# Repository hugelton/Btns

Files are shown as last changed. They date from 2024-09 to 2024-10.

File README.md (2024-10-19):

# Btns
Buttons board compatible with monome grid



## Overview
Btns is a clone of [Monome Grid]([url](https://monome.org)).

**⚠️ It doesn't support 16 levels of LED grey scale. It just turns on or off. **

## Make
### Hardware
Make your board from the gerber.

#### BOM
+ Raspberry Pi Pico (or same footprint clones) * 1
+ TSHD-T-2.8T2 SMD Tact switch with LED * 64
+ 1N4148W (SOD-123) SMD diode * 64
+ TM1640 LED segments driver * 1
+ 10k THT resistor * 2
+ 10ohm THT resistor * 1
+ MPU-6050 (optional for tilt mod)
+ VXO7803-500 (optional)
+ Eurorack 16pin Bus Conn (optional)

### Firmware
upload the firmware to Pico from [Release]([url](https://github.com/hugelton/Btns/releases/tag/0.3)). 

### Test (on Norns)
Please use okyeron's [grid-test](https://github.com/okyeron/grid-test) 

```
;install https://github.com/okyeron/grid-test
```

### Plans
+ support MPU-6050 (tilt)
+ support multi-PWM
+ support other buttons

## Acknowledgments
Based on okyeron's [neotrellis-monome](https://github.com/okyeron/neotrellis-monome/) project.

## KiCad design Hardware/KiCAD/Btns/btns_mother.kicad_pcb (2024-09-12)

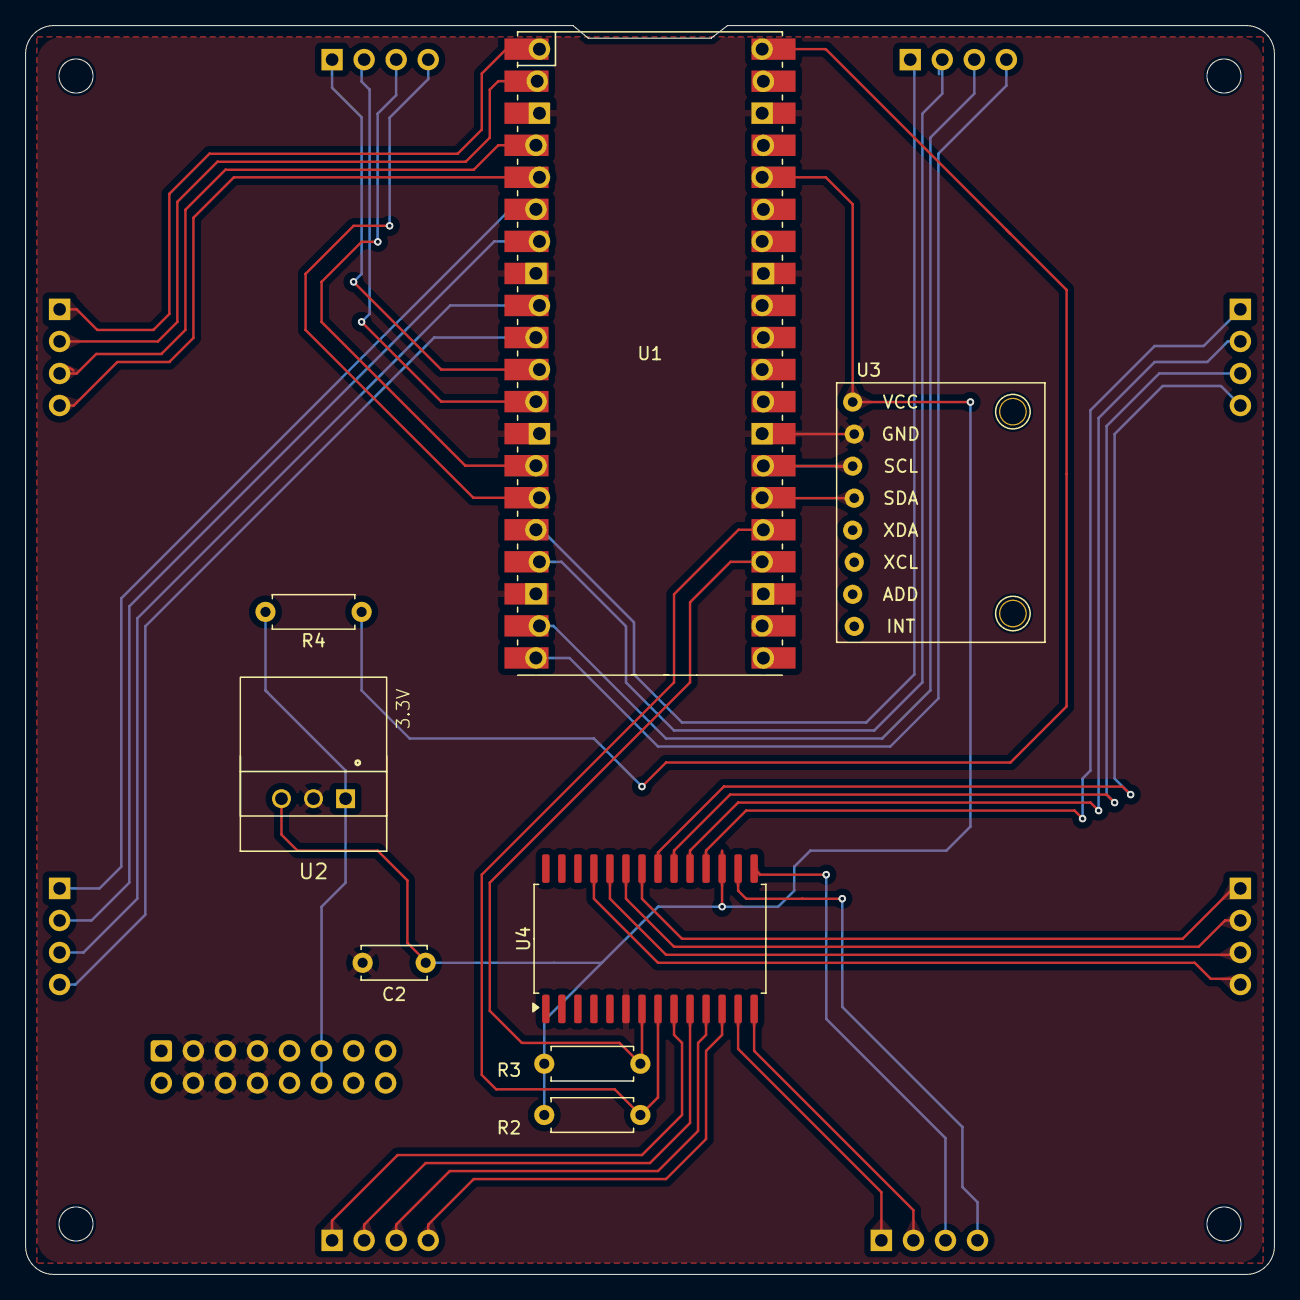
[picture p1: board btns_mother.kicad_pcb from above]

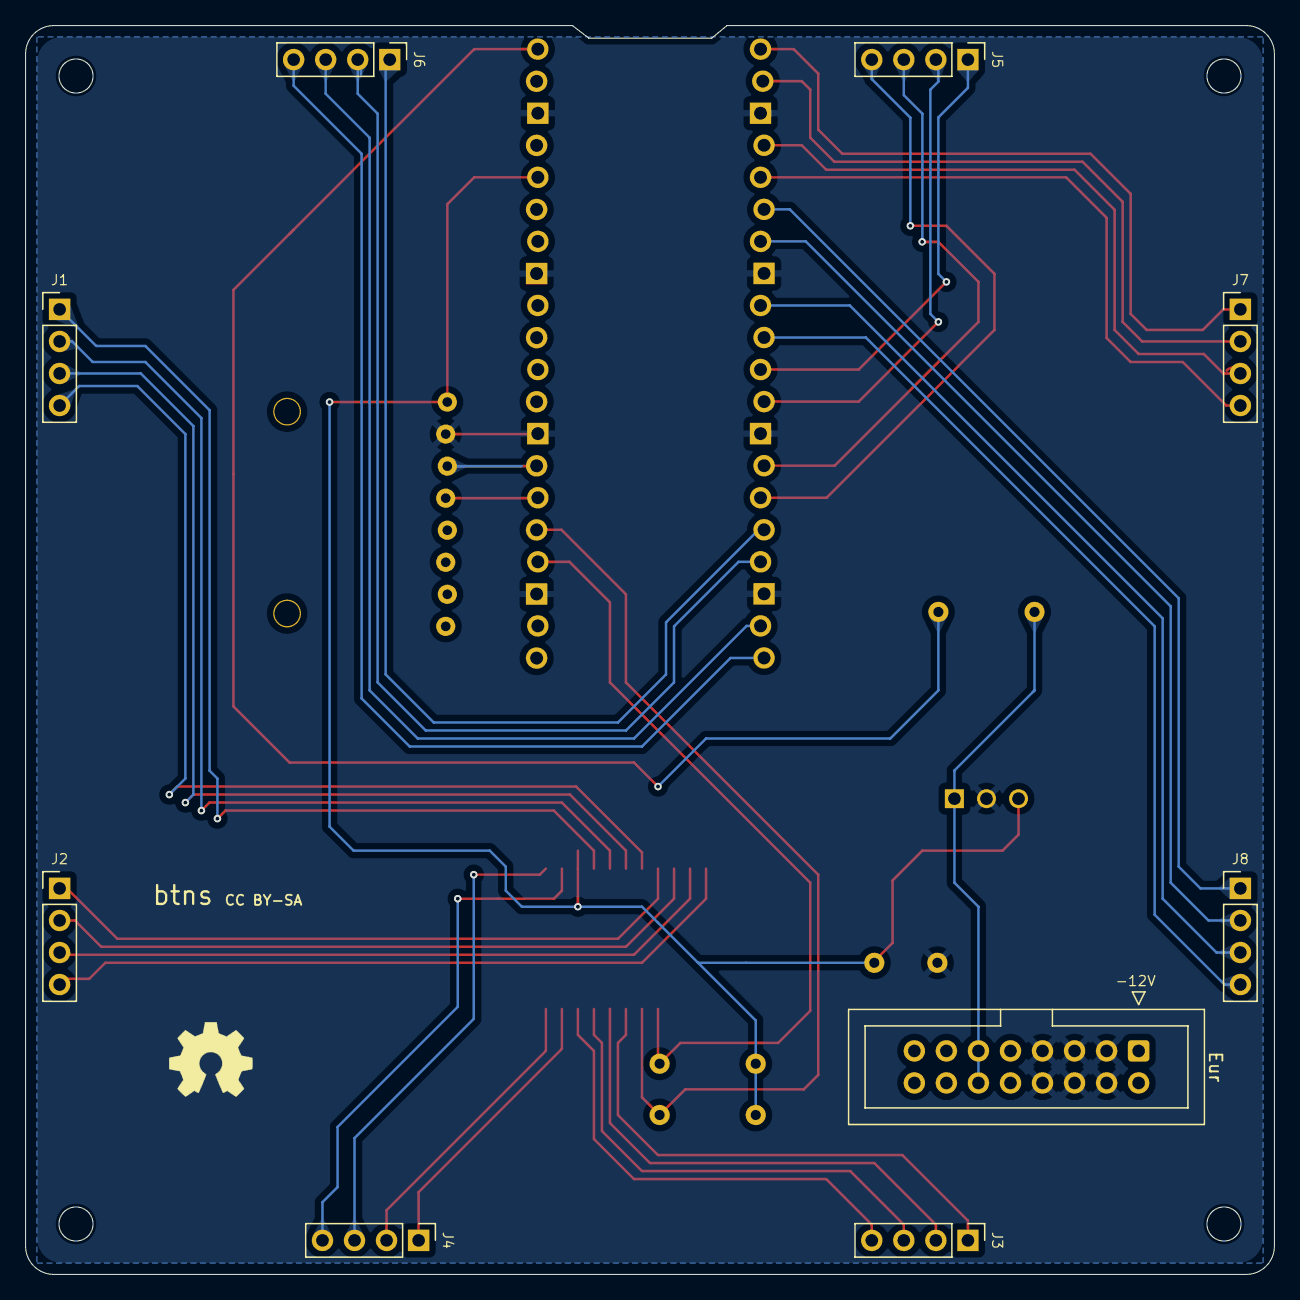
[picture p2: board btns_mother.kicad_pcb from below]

Board: 2 copper layers, 99.0 x 99.0 mm, 17 parts (9 on the bottom side), 40 nets.

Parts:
C2: 10uF; C_Disc_D5.0mm_W2.5mm_P5.00mm
Eur: IDC-Header_2x08_P2.54mm_Vertical
J1, J2, J3, J4, J5, J6, J7, J8: Conn_01x04_Pin; PinHeader_1x04_P2.54mm_Vertical
R2, R3: 10k; R_Axial_DIN0207_L6.3mm_D2.5mm_P7.62mm_Horizontal
R4: 10; R_Axial_DIN0207_L6.3mm_D2.5mm_P7.62mm_Horizontal
U1: Pico; RPi_Pico
U2: VX78_O78
U3: module_mpu6050
U4: TM1640; SOP-28_8.4x18.16mm_P1.27mm

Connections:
+3V3: C2.1, R2.1, R3.1, U1.36 (3V3), U2.3 (+VOUT/GND), U3.1 (VCC), U4.17 (VDD)
GND: C2.2, Eur.3, Eur.4, Eur.5, Eur.6, Eur.7, Eur.8, U1.3 (GND), U1.8 (GND), U1.13 (GND), U1.18 (GND), U1.23 (GND), U1.28 (GND), U1.33 (AGND), U1.38 (GND), U2.2 (GND/-VOUT), U3.2 (GND), U4.6 (VSS)
I2C0_SCL: U1.27 (GPIO21), U3.3 (SCL)
I2C0_SDA: U1.26 (GPIO20), U3.4 (SDA)
LED_COL_1: J3.1, U4.9 (SEG1)
LED_COL_2: J3.2, U4.10 (SEG2)
LED_COL_3: J3.3, U4.11 (SEG3)
LED_COL_4: J3.4, U4.12 (SEG4)
LED_COL_5: J4.1, U4.13 (SEG5)
LED_COL_6: J4.2, U4.14 (SEG6)
LED_COL_7: J4.3, U4.15 (SEG7)
LED_COL_8: J4.4, U4.16 (SEG8)
LED_ROW_1: J1.1, U4.18 (GRID1)
LED_ROW_2: J1.2, U4.19 (GRID2)
LED_ROW_3: J1.3, U4.20 (GRID3)
LED_ROW_4: J1.4, U4.21 (GRID4)
LED_ROW_5: J2.1, U4.22 (GRID5)
LED_ROW_6: J2.2, U4.23 (GRID6)
LED_ROW_7: J2.3, U4.24 (GRID7)
LED_ROW_8: J2.4, U4.25 (GRID8)
unnamed: Eur.11, Eur.12, R4.2, U2.1 (+VIN)
SW_COL_1: J5.1, U1.11 (GPIO8)
SW_COL_2: J5.2, U1.12 (GPIO9)
SW_COL_3: J5.3, U1.14 (GPIO10)
SW_COL_4: J5.4, U1.15 (GPIO11)
SW_COL_5: J6.1, U1.16 (GPIO12)
SW_COL_6: J6.2, U1.17 (GPIO13)
SW_COL_7: J6.3, U1.19 (GPIO14)
SW_COL_8: J6.4, U1.20 (GPIO15)
SW_ROW_1: J7.1, U1.1 (GPIO0)
SW_ROW_2: J7.2, U1.2 (GPIO1)
SW_ROW_3: J7.3, U1.4 (GPIO2)
SW_ROW_4: J7.4, U1.5 (GPIO3)
SW_ROW_5: J8.1, U1.6 (GPIO4)
SW_ROW_6: J8.2, U1.7 (GPIO5)
SW_ROW_7: J8.3, U1.9 (GPIO6)
SW_ROW_8: J8.4, U1.10 (GPIO7)
TM_D: R3.2, U1.24 (GPIO18), U4.7 (DIN)
TM_SCLK: R2.2, U1.25 (GPIO19), U4.8 (SCLK)
VBUS: R4.1, U1.40 (VBUS)

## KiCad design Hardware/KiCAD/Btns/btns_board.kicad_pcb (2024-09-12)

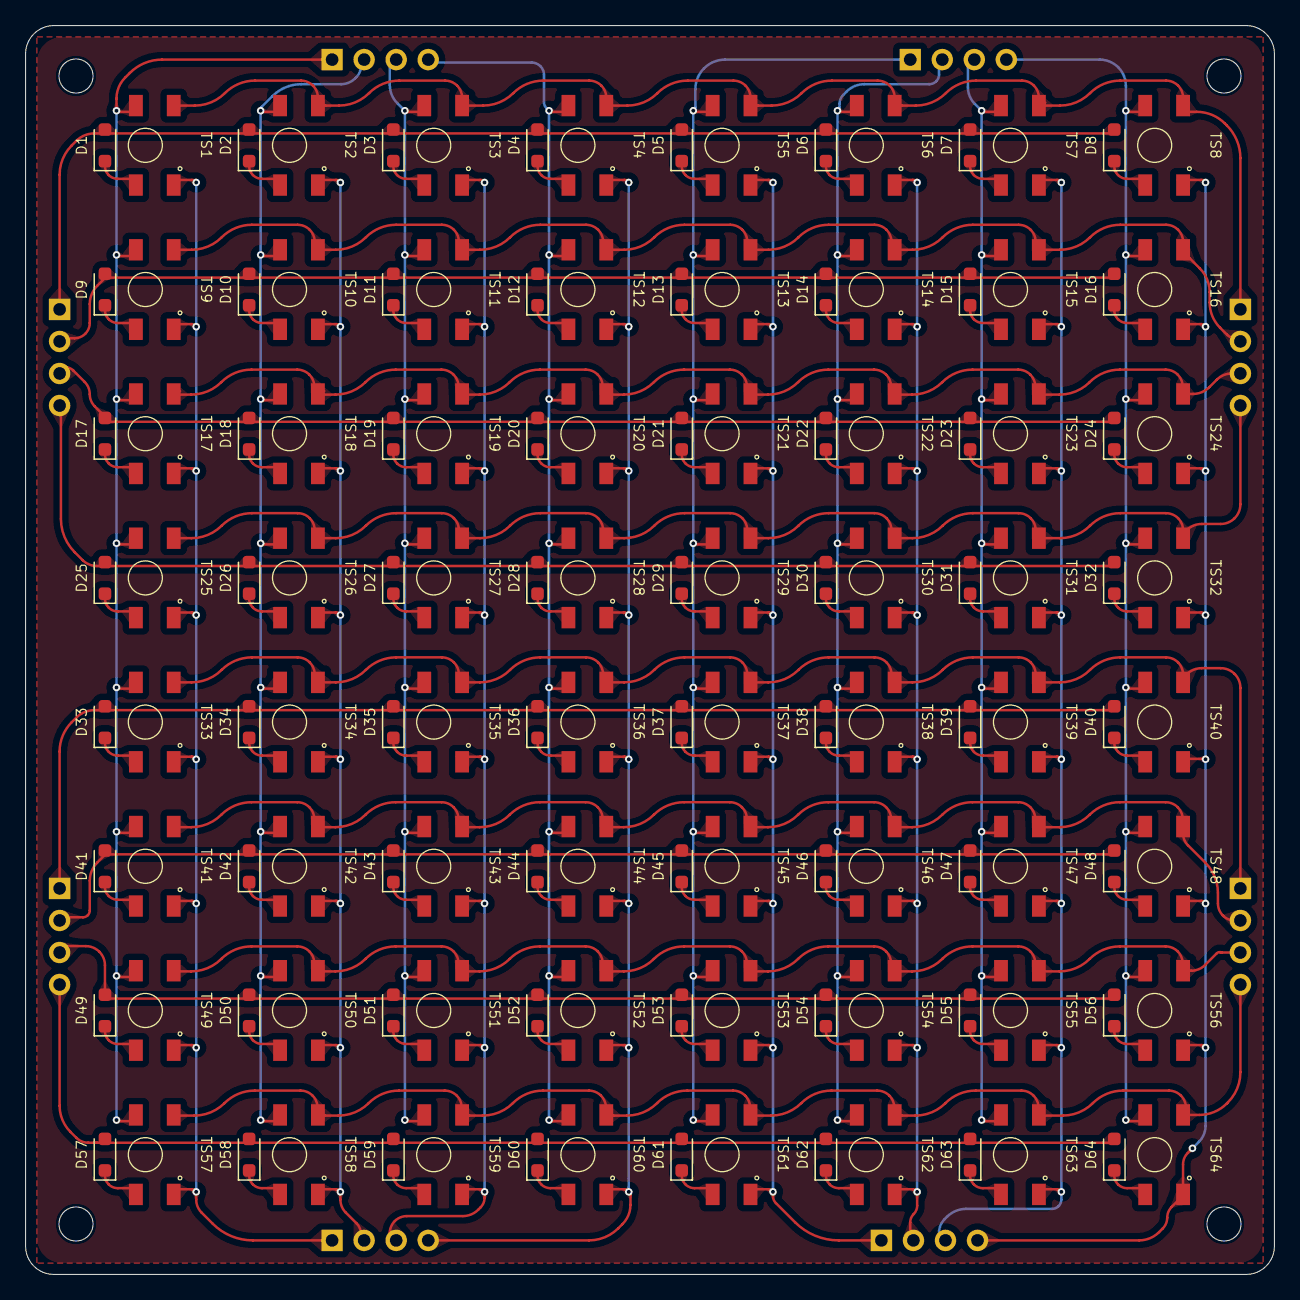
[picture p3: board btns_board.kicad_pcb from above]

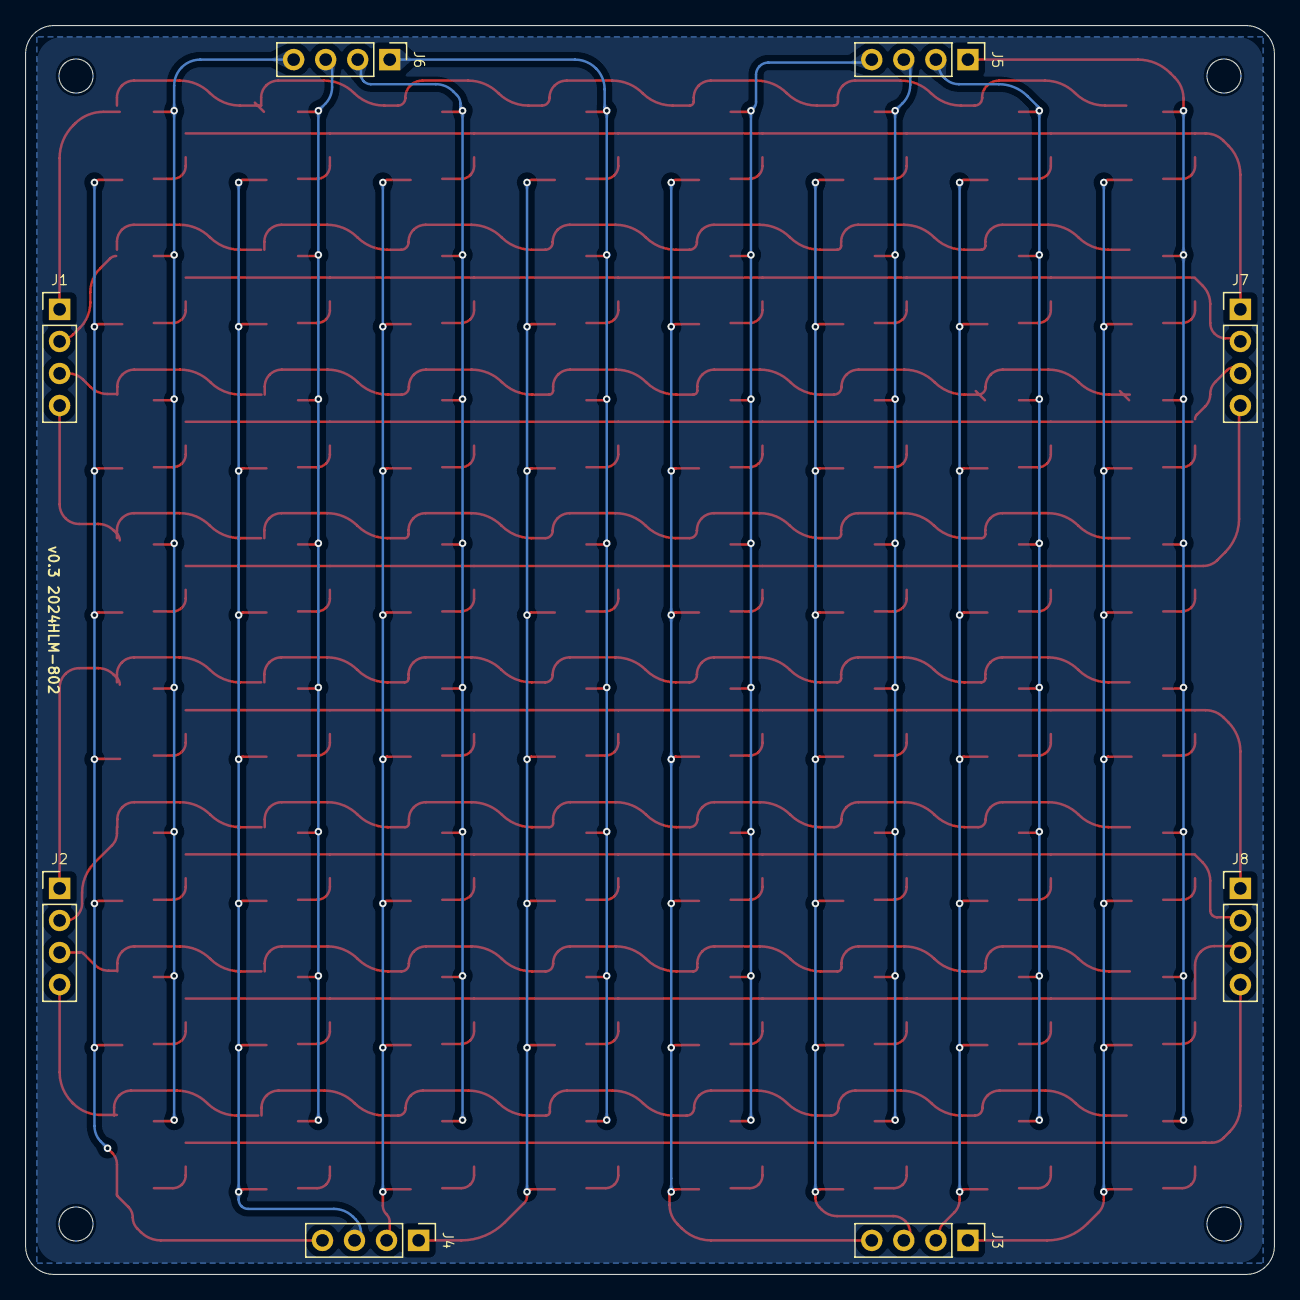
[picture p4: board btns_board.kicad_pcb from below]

Board: 2 copper layers, 99.0 x 99.0 mm, 136 parts (8 on the bottom side), 96 nets.

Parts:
D1, D2, D3, D4, D5, D6, D7, D8, D9, D10, D11, D12, D13, D14, D15, D16, D17, D18, D19, D20, D21, D22, D23, D24, D25, D26, D27, D28, D29, D30, D31, D32, D33, D34, D35, D36, D37, D38, D39, D40, D41, D42, D43, D44, D45, D46, D47, D48, D49, D50, D51, D52, D53, D54, D55, D56, D57, D58, D59, D60, D61, D62, D63, D64: 1N4148WS; D_SOD-323_HandSoldering
J1, J2, J3, J4, J5, J6, J7, J8: Conn_01x04_Pin; PinHeader_1x04_P2.54mm_Vertical
TS1, TS2, TS3, TS4, TS5, TS6, TS7, TS8, TS9, TS10, TS11, TS12, TS13, TS14, TS15, TS16, TS17, TS18, TS19, TS20, TS21, TS22, TS23, TS24, TS25, TS26, TS27, TS28, TS29, TS30, TS31, TS32, TS33, TS34, TS35, TS36, TS37, TS38, TS39, TS40, TS41, TS42, TS43, TS44, TS45, TS46, TS47, TS48, TS49, TS50, TS51, TS52, TS53, TS54, TS55, TS56, TS57, TS58, TS59, TS60, TS61, TS62, TS63, TS64: TSHD-T-2.8T2--6H

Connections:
LED_COL_1: J3.1, TS1.3 (L1), TS9.3 (L1), TS17.3 (L1), TS25.3 (L1), TS33.3 (L1), TS41.3 (L1), TS49.3 (L1), TS57.3 (L1)
LED_COL_2: J3.2, TS2.3 (L1), TS10.3 (L1), TS18.3 (L1), TS26.3 (L1), TS34.3 (L1), TS42.3 (L1), TS50.3 (L1), TS58.3 (L1)
LED_COL_3: J3.3, TS3.3 (L1), TS11.3 (L1), TS19.3 (L1), TS27.3 (L1), TS35.3 (L1), TS43.3 (L1), TS51.3 (L1), TS59.3 (L1)
LED_COL_4: J3.4, TS4.3 (L1), TS12.3 (L1), TS20.3 (L1), TS28.3 (L1), TS36.3 (L1), TS44.3 (L1), TS52.3 (L1), TS60.3 (L1)
LED_COL_5: J4.1, TS5.3 (L1), TS13.3 (L1), TS21.3 (L1), TS29.3 (L1), TS37.3 (L1), TS45.3 (L1), TS53.3 (L1), TS61.3 (L1)
LED_COL_6: J4.2, TS6.3 (L1), TS14.3 (L1), TS22.3 (L1), TS30.3 (L1), TS38.3 (L1), TS46.3 (L1), TS54.3 (L1), TS62.3 (L1)
LED_COL_7: J4.3, TS7.3 (L1), TS15.3 (L1), TS23.3 (L1), TS31.3 (L1), TS39.3 (L1), TS47.3 (L1), TS55.3 (L1), TS63.3 (L1)
LED_COL_8: J4.4, TS8.3 (L1), TS16.3 (L1), TS24.3 (L1), TS32.3 (L1), TS40.3 (L1), TS48.3 (L1), TS56.3 (L1), TS64.3 (L1)
LED_ROW_1: J1.1, TS1.4 (L2), TS2.4 (L2), TS3.4 (L2), TS4.4 (L2), TS5.4 (L2), TS6.4 (L2), TS7.4 (L2), TS8.4 (L2)
LED_ROW_2: J1.2, TS9.4 (L2), TS10.4 (L2), TS11.4 (L2), TS12.4 (L2), TS13.4 (L2), TS14.4 (L2), TS15.4 (L2), TS16.4 (L2)
LED_ROW_3: J1.3, TS17.4 (L2), TS18.4 (L2), TS19.4 (L2), TS20.4 (L2), TS21.4 (L2), TS22.4 (L2), TS23.4 (L2), TS24.4 (L2)
LED_ROW_4: J1.4, TS25.4 (L2), TS26.4 (L2), TS27.4 (L2), TS28.4 (L2), TS29.4 (L2), TS30.4 (L2), TS31.4 (L2), TS32.4 (L2)
LED_ROW_5: J2.1, TS33.4 (L2), TS34.4 (L2), TS35.4 (L2), TS36.4 (L2), TS37.4 (L2), TS38.4 (L2), TS39.4 (L2), TS40.4 (L2)
LED_ROW_6: J2.2, TS41.4 (L2), TS42.4 (L2), TS43.4 (L2), TS44.4 (L2), TS45.4 (L2), TS46.4 (L2), TS47.4 (L2), TS48.4 (L2)
LED_ROW_7: J2.3, TS49.4 (L2), TS50.4 (L2), TS51.4 (L2), TS52.4 (L2), TS53.4 (L2), TS54.4 (L2), TS55.4 (L2), TS56.4 (L2)
LED_ROW_8: J2.4, TS57.4 (L2), TS58.4 (L2), TS59.4 (L2), TS60.4 (L2), TS61.4 (L2), TS62.4 (L2), TS63.4 (L2), TS64.4 (L2)
unnamed: D1.1 (K), TS1.1
unnamed: D2.1 (K), TS2.1
unnamed: D3.1 (K), TS3.1
unnamed: D4.1 (K), TS4.1
unnamed: D5.1 (K), TS5.1
unnamed: D6.1 (K), TS6.1
unnamed: D7.1 (K), TS7.1
unnamed: D8.1 (K), TS8.1
unnamed: D9.1 (K), TS9.1
unnamed: D10.1 (K), TS10.1
unnamed: D11.1 (K), TS11.1
unnamed: D12.1 (K), TS12.1
unnamed: D13.1 (K), TS13.1
unnamed: D14.1 (K), TS14.1
unnamed: D15.1 (K), TS15.1
unnamed: D16.1 (K), TS16.1
unnamed: D17.1 (K), TS17.1
unnamed: D18.1 (K), TS18.1
unnamed: D19.1 (K), TS19.1
unnamed: D20.1 (K), TS20.1
unnamed: D21.1 (K), TS21.1
unnamed: D22.1 (K), TS22.1
unnamed: D23.1 (K), TS23.1
unnamed: D24.1 (K), TS24.1
unnamed: D25.1 (K), TS25.1
unnamed: D26.1 (K), TS26.1
unnamed: D27.1 (K), TS27.1
unnamed: D28.1 (K), TS28.1
unnamed: D29.1 (K), TS29.1
unnamed: D30.1 (K), TS30.1
unnamed: D31.1 (K), TS31.1
unnamed: D32.1 (K), TS32.1
unnamed: D33.1 (K), TS33.1
unnamed: D34.1 (K), TS34.1
unnamed: D35.1 (K), TS35.1
unnamed: D36.1 (K), TS36.1
unnamed: D37.1 (K), TS37.1
unnamed: D38.1 (K), TS38.1
unnamed: D39.1 (K), TS39.1
unnamed: D40.1 (K), TS40.1
unnamed: D41.1 (K), TS41.1
unnamed: D42.1 (K), TS42.1
unnamed: D43.1 (K), TS43.1
unnamed: D44.1 (K), TS44.1
unnamed: D45.1 (K), TS45.1
unnamed: D46.1 (K), TS46.1
unnamed: D47.1 (K), TS47.1
unnamed: D48.1 (K), TS48.1
unnamed: D49.1 (K), TS49.1
unnamed: D50.1 (K), TS50.1
unnamed: D51.1 (K), TS51.1
unnamed: D52.1 (K), TS52.1
unnamed: D53.1 (K), TS53.1
unnamed: D54.1 (K), TS54.1
unnamed: D55.1 (K), TS55.1
unnamed: D56.1 (K), TS56.1
unnamed: D57.1 (K), TS57.1
unnamed: D58.1 (K), TS58.1
unnamed: D59.1 (K), TS59.1
unnamed: D60.1 (K), TS60.1
unnamed: D61.1 (K), TS61.1
unnamed: D62.1 (K), TS62.1
unnamed: D63.1 (K), TS63.1
unnamed: D64.1 (K), TS64.1
SW_COL_1: J5.1, TS1.2, TS9.2, TS17.2, TS25.2, TS33.2, TS41.2, TS49.2, TS57.2
SW_COL_2: J5.2, TS2.2, TS10.2, TS18.2, TS26.2, TS34.2, TS42.2, TS50.2, TS58.2
SW_COL_3: J5.3, TS3.2, TS11.2, TS19.2, TS27.2, TS35.2, TS43.2, TS51.2, TS59.2
SW_COL_4: J5.4, TS4.2, TS12.2, TS20.2, TS28.2, TS36.2, TS44.2, TS52.2, TS60.2
SW_COL_5: J6.1, TS5.2, TS13.2, TS21.2, TS29.2, TS37.2, TS45.2, TS53.2, TS61.2
SW_COL_6: J6.2, TS6.2, TS14.2, TS22.2, TS30.2, TS38.2, TS46.2, TS54.2, TS62.2
SW_COL_7: J6.3, TS7.2, TS15.2, TS23.2, TS31.2, TS39.2, TS47.2, TS55.2, TS63.2
SW_COL_8: J6.4, TS8.2, TS16.2, TS24.2, TS32.2, TS40.2, TS48.2, TS56.2, TS64.2
SW_ROW_1: D1.2 (A), D2.2 (A), D3.2 (A), D4.2 (A), D5.2 (A), D6.2 (A), D7.2 (A), D8.2 (A), J7.1
SW_ROW_2: D9.2 (A), D10.2 (A), D11.2 (A), D12.2 (A), D13.2 (A), D14.2 (A), D15.2 (A), D16.2 (A), J7.2
SW_ROW_3: D17.2 (A), D18.2 (A), D19.2 (A), D20.2 (A), D21.2 (A), D22.2 (A), D23.2 (A), D24.2 (A), J7.3
SW_ROW_4: D25.2 (A), D26.2 (A), D27.2 (A), D28.2 (A), D29.2 (A), D30.2 (A), D31.2 (A), D32.2 (A), J7.4
SW_ROW_5: D33.2 (A), D34.2 (A), D35.2 (A), D36.2 (A), D37.2 (A), D38.2 (A), D39.2 (A), D40.2 (A), J8.1
SW_ROW_6: D41.2 (A), D42.2 (A), D43.2 (A), D44.2 (A), D45.2 (A), D46.2 (A), D47.2 (A), D48.2 (A), J8.2
SW_ROW_7: D49.2 (A), D50.2 (A), D51.2 (A), D52.2 (A), D53.2 (A), D54.2 (A), D55.2 (A), D56.2 (A), J8.3
SW_ROW_8: D57.2 (A), D58.2 (A), D59.2 (A), D60.2 (A), D61.2 (A), D62.2 (A), D63.2 (A), D64.2 (A), J8.4

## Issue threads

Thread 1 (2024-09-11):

CAD files for footprint switching?

KeLaiFu, 2024-09-11:
thanks for sharing this, it's certainly going to make many peoples access to grids much easier.

Would it be possible for you to share the CAD files so we can switch out the button footprint? I havnt been able to find those particular buttons in my part of the globe, but there's planty of similar alternatives.

Cheers!

kurogedelic, 2024-09-12:
Added KiCAD file.
I used a very local Taiwanese switch so a global alternative would be welcome!

KeLaiFu, 2024-09-12:
excellent, thanks!
I'm in China, so maybe not so global but more options are always better.

dennisdebel, 2025-09-14:
> excellent, thanks! I'm in China, so maybe not so global but more options are always better.

Hi! I am in mainland as well and I was wondering what alternative switches you found and if you ever got around to footprint swapping?

Closed 2024-09-13.

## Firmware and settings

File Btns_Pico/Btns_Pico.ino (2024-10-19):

// Btns 0.6
// by Leo Kuroshita for Hügelton instruments.
// Modified to include MPU-6050 tilt support

#include "MonomeSerialDevice.h"
#include <TM1640.h>
#include <TM16xxMatrix.h>
#include <Arduino.h>
#include <Adafruit_TinyUSB.h>
#include <Adafruit_MPU6050.h>
#include <Adafruit_Sensor.h>
#include <Wire.h>

#define NUM_ROWS 8
#define NUM_COLS 8
#define BRIGHTNESS 127

#define DEFAULT_ROTATION 0
#define DEFAULT_FLIP_HORIZONTAL false
#define DEFAULT_FLIP_VERTICAL false

const uint8_t ROW_PINS[NUM_ROWS] = {0, 1, 2, 3, 4, 5, 6, 7};  // GPIO00-GPIO07
const uint8_t COL_PINS[NUM_COLS] = {8, 9, 10, 11, 12, 13, 14, 15};  // GPIO8-GPIO15

TM1640 module(18, 19);  // DIN=18, CLK=19
TM16xxMatrix matrix(&module, NUM_COLS, NUM_ROWS);

bool isInited = false;
String deviceID = "btns";
String serialNum = "m4216124";

char mfgstr[32] = "monome";
char prodstr[32] = "monome";
char serialstr[32] = "m4216124";

MonomeSerialDevice mdp;
Adafruit_MPU6050 mpu;

bool buttonStates[NUM_ROWS][NUM_COLS] = {0};

int gridRotation = DEFAULT_ROTATION;
bool flipHorizontal = DEFAULT_FLIP_HORIZONTAL;
bool flipVertical = DEFAULT_FLIP_VERTICAL;

void mapButtonToLED(int buttonRow, int buttonCol, int &ledRow, int &ledCol) {
    // Handle button to LED mapping based on rotation and flipping
    ledRow = buttonRow;
    ledCol = buttonCol;

    // Apply rotation
    switch (gridRotation) {
        case 0: // No rotation
            break;
        case 1: // 90 degree rotation
            {
                int temp = ledRow;
                ledRow = ledCol;
                ledCol = NUM_COLS - 1 - temp;
            }
            break;
        case 2: // 180 degree rotation
            ledRow = NUM_ROWS - 1 - ledRow;
            ledCol = NUM_COLS - 1 - ledCol;
            break;
        case 3: // 270 degree rotation
            {
                int temp = ledRow;
                ledRow = NUM_ROWS - 1 - ledCol;
                ledCol = temp;
            }
            break;
    }

    // Apply flipping
    if (flipHorizontal) ledCol = NUM_COLS - 1 - ledCol;
    if (flipVertical) ledRow = NUM_ROWS - 1 - ledRow;
}

bool detectGridOrientation() {
    bool buttonPressed = false;
    // Scan to check which button is pressed
    for (int col = 0; col < NUM_COLS; col++) {
        digitalWrite(COL_PINS[col], LOW);
        for (int row = 0; row < NUM_ROWS; row++) {
            if (!digitalRead(ROW_PINS[row])) {
                buttonPressed = true;
                // Set grid rotation based on pressed button
                if (row == 0 && col == 0) {
                    gridRotation = 0;
                } else if (row == 0 && col == NUM_COLS - 1) {
                    gridRotation = 1;
                } else if (row == NUM_ROWS - 1 && col == NUM_COLS - 1) {
                    gridRotation = 2;
                } else if (row == NUM_ROWS - 1 && col == 0) {
                    gridRotation = 3;
                }
                digitalWrite(COL_PINS[col], HIGH);
                return buttonPressed;
            }
        }
        digitalWrite(COL_PINS[col], HIGH);
    }
    // If no button is pressed, set default orientation
    gridRotation = DEFAULT_ROTATION;
    return buttonPressed;
}

void setup() {
    USBDevice.setManufacturerDescriptor(mfgstr);
    USBDevice.setProductDescriptor(prodstr);
    USBDevice.setSerialDescriptor(serialstr);

    pinMode(LED_BUILTIN, OUTPUT);

    for (int i = 0; i < NUM_ROWS; i++) {
        pinMode(ROW_PINS[i], INPUT_PULLUP);
    }
    for (int i = 0; i < NUM_COLS; i++) {
        pinMode(COL_PINS[i], OUTPUT);
        digitalWrite(COL_PINS[i], HIGH);
    }

    detectGridOrientation();

    module.clearDisplay();
    matrix.setAll(false);
    module.setupDisplay(true, BRIGHTNESS);

    mdp.isMonome = true;
    mdp.deviceID = deviceID;
    mdp.setupAsGrid(NUM_ROWS, NUM_COLS);

    isInited = true;
    mdp.poll();

    // Send grid size and rotation information
    mdp.sendSysSize();
    mdp.sendSysRotation();

    // Initialize MPU-6050
    Wire.setSCL(21);
    Wire.setSDA(20);
    Wire.begin();

    if (!mpu.begin()) {
        Serial.println("Failed to find MPU6050 chip");
        while (1) {
            delay(10);
        }
    }
    Serial.println("MPU6050 Found!");

    mpu.setGyroRange(MPU6050_RANGE_500_DEG);
    mpu.setFilterBandwidth(MPU6050_BAND_21_HZ);

    // Set tilt sensor 0 as active
    mdp.setTiltActive(0, true);
}

void loop() {
    static unsigned long lastCheck = 0;
    static unsigned long lastTiltCheck = 0;
    unsigned long currentMillis = millis();

    mdp.poll();

    if (currentMillis - lastCheck >= 15) {
        lastCheck = currentMillis;
        scanButtonMatrix();
        updateLEDMatrix();
    }

    // Send tilt data every 100ms
    if (currentMillis - lastTiltCheck >= 100) {
        lastTiltCheck = currentMillis;
        sendTiltData();
    }
}

void scanButtonMatrix() {
    for (int row = 0; row < NUM_ROWS; row++) {
        for (int col = 0; col < NUM_COLS; col++) {
            digitalWrite(COL_PINS[col], LOW);
            bool currentState = !digitalRead(ROW_PINS[row]);
            digitalWrite(COL_PINS[col], HIGH);

            int ledRow, ledCol;
            mapButtonToLED(row, col, ledRow, ledCol);

            if (currentState != buttonStates[row][col]) {
                mdp.sendGridKey(ledCol, ledRow, currentState);
                buttonStates[row][col] = currentState;
            }
        }
    }
}

void updateLEDMatrix() {
    for (int row = 0; row < NUM_ROWS; row++) {
        for (int col = 0; col < NUM_COLS; col++) {
            int ledRow, ledCol;
            mapButtonToLED(row, col, ledRow, ledCol);
            matrix.setPixel(ledRow, ledCol, mdp.leds[row * NUM_COLS + col] > 0);
        }
    }
}

void sendTiltData() {
    sensors_event_t a, g, temp;
    mpu.getEvent(&a, &g, &temp);

    // Scale gyro data to 16-bit integer range
    int16_t x = (int16_t)(g.gyro.x * 1000);
    int16_t y = (int16_t)(g.gyro.y * 1000);
    int16_t z = (int16_t)(g.gyro.z * 1000);

    mdp.sendTiltEvent(0, x, y, z);
}

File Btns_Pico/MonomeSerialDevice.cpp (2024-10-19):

#include "MonomeSerialDevice.h"
#include "debug.h"

MonomeSerialDevice::MonomeSerialDevice() {}

void MonomeSerialDevice::initialize() {
  active = false;
  isMonome = false;
  isGrid = true;
  rows = 0;
  columns = 0;
  encoders = 0;
  //clearQueue();
  clearAllLeds();
  arcDirty = false;
  gridDirty = false;
}

void MonomeSerialDevice::setupAsGrid(uint8_t _rows, uint8_t _columns) {
  initialize();
  active = true;
  isMonome = true;
  isGrid = true;
  rows = _rows;
  columns = _columns;
  gridDirty = true;
  debugfln(INFO, "GRID rows: %d columns %d", rows, columns);
}

void MonomeSerialDevice::setupAsArc(uint8_t _encoders) {
  initialize();
  active = true;
  isMonome = true;
  isGrid = false;
  encoders = _encoders;
  arcDirty = true;
  debugfln(INFO, "ARC encoders: %d", encoders);
}

void MonomeSerialDevice::setTiltActive(uint8_t sensor, bool active) {
  if (sensor < 4) {
    tiltActive[sensor] = active;
  }
}

void MonomeSerialDevice::sendTiltEvent(uint8_t sensor, int16_t x, int16_t y, int16_t z) {
    if (sensor < 4 && tiltActive[sensor]) {
        lastTiltX[sensor] = x;
        lastTiltY[sensor] = y;
        lastTiltZ[sensor] = z;

        Serial.write((uint8_t)0x81);  // tiltイベントのプレフィックス
        Serial.write(sensor);
        Serial.write((uint8_t)(x >> 8));
        Serial.write((uint8_t)(x & 0xFF));
        Serial.write((uint8_t)(y >> 8));
        Serial.write((uint8_t)(y & 0xFF));
        Serial.write((uint8_t)(z >> 8));
        Serial.write((uint8_t)(z & 0xFF));
    }
}


void MonomeSerialDevice::getDeviceInfo() {
  //debugln(INFO, "MonomeSerialDevice::getDeviceInfo");
  Serial.write(uint8_t(0));
}

void MonomeSerialDevice::poll() {
  //while (isMonome && Serial.available()) { processSerial(); };
  if (Serial.available()) {
    processSerial();
  }
  //Serial.println("processSerial");
}


void MonomeSerialDevice::setAllLEDs(int value) {
  for (int i = 0; i < MAXLEDCOUNT; i++) leds[i] = value;
}

void MonomeSerialDevice::setGridLed(uint8_t x, uint8_t y, uint8_t level) {
  //    int index = x + (y * columns);
  //    if (index < MAXLEDCOUNT) leds[index] = level;

  if (x < columns && y < rows) {
    uint32_t index = y * columns + x;
    leds[index] = level;
  }
  //debugfln(INFO, "LED index: %d x %d y %d", index, x, y);
}

void MonomeSerialDevice::clearGridLed(uint8_t x, uint8_t y) {
  setGridLed(x, y, 0);
  //Serial.println("clearGridLed");
}

void MonomeSerialDevice::setArcLed(uint8_t enc, uint8_t led, uint8_t level) {
  int index = led + (enc << 6);
  if (index < MAXLEDCOUNT) leds[index] = level;
  //Serial.println("setArcLed");
}

void MonomeSerialDevice::clearArcLed(uint8_t enc, uint8_t led) {
  setArcLed(enc, led, 0);
  //Serial.println("clearArcLed");
}

void MonomeSerialDevice::clearAllLeds() {
  for (int i = 0; i < MAXLEDCOUNT; i++) leds[i] = 0;
  //Serial.println("clearAllLeds");
}

void MonomeSerialDevice::clearArcRing(uint8_t ring) {
  for (int i = ring << 6, upper = i + 64; i < upper; i++) leds[i] = 0;
  //Serial.println("clearArcRing");
}

void MonomeSerialDevice::refreshGrid() {
  gridDirty = true;
  //Serial.println("refreshGrid");
}

void MonomeSerialDevice::refreshArc() {
  arcDirty = true;
  //Serial.println("refreshArc");
}

void MonomeSerialDevice::sendSysSize() {
  Serial.write((uint8_t)0x05);  // system / get grid size
  Serial.write((uint8_t)columns);
  Serial.write((uint8_t)rows);
}

void MonomeSerialDevice::sendSysRotation() {
  // Note: The original Monome protocol doesn't have a direct command for rotation.
  // This is a custom implementation. You may need to adjust how the host interprets this.
  Serial.write((uint8_t)0x0F);  // Using 0x0F (system / report firmware version) as a custom command
  Serial.write((uint8_t)0xF0);  // Custom identifier for rotation
  Serial.write((uint8_t)gridRotation);
}

void MonomeSerialDevice::refresh() {
  /*
    uint8_t buf[35];
    int ind, led;

    if (gridDirty) {
        //Serial.println("gridDirty");
        buf[0] = 0x1A;
        buf[1] = 0;
        buf[2] = 0;

        ind = 3;
        for (int y = 0; y < 8; y++)
            for (int x = 0; x < 8; x += 2) {
                led = (y << 4) + x;
                buf[ind++] = (leds[led] << 4) | leds[led + 1];
            }
        Serial.write(buf, 35);
        
        ind = 3;
        buf[1] = 8;
        for (int y = 0; y < 8; y++)
            for (int x = 8; x < 16; x += 2) {
                led = (y << 4) + x;
                buf[ind++] = (leds[led] << 4) | leds[led + 1];
            }
        Serial.write(buf, 35);
        
        ind = 3;
        buf[1] = 0;
        buf[2] = 8;
        for (int y = 8; y < 16; y++)
            for (int x = 0; x < 8; x += 2) {
                led = (y << 4) + x;
                buf[ind++] = (leds[led] << 4) | leds[led + 1];
            }
        Serial.write(buf, 35);

        ind = 3;
        buf[1] = 8;
        for (int y = 8; y < 16; y++)
            for (int x = 8; x < 16; x += 2) {
                led = (y << 4) + x;
                buf[ind++] = (leds[led] << 4) | leds[led + 1];
            }
        Serial.write(buf, 35);
        
        gridDirty = false;
    }

    if (arcDirty) {
        //Serial.print("arcDirty");
        buf[0] = 0x92;

        buf[1] = 0;
        ind = 2;
        for (led = 0; led < 64; led += 2)
            buf[ind++] = (leds[led] << 4) | leds[led + 1];
        Serial.write(buf, 34);
        
        buf[1] = 1;
        ind = 2;
        for (led = 64; led < 128; led += 2)
            buf[ind++] = (leds[led] << 4) | leds[led + 1];
        Serial.write(buf, 34);

        buf[1] = 2;
        ind = 2;
        for (led = 128; led < 192; led += 2)
            buf[ind++] = (leds[led] << 4) | leds[led + 1];
        Serial.write(buf, 34);
        
        buf[1] = 3;
        ind = 2;
        for (led = 192; led < 256; led += 2)
            buf[ind++] = (leds[led] << 4) | leds[led + 1];
        Serial.write(buf, 34);
        
        buf[1] = 4;
        ind = 2;
        for (led = 256; led < 320; led += 2)
            buf[ind++] = (leds[led] << 4) | leds[led + 1];
        Serial.write(buf, 34);

        buf[1] = 5;
        ind = 2;
        for (led = 320; led < 384; led += 2)
            buf[ind++] = (leds[led] << 4) | leds[led + 1];
        Serial.write(buf, 34);

        buf[1] = 6;
        ind = 2;
        for (led = 384; led < 448; led += 2)
            buf[ind++] = (leds[led] << 4) | leds[led + 1];
        Serial.write(buf, 34);

        buf[1] = 7;
        ind = 2;
        for (led = 448; led < 512; led += 2)
            buf[ind++] = (leds[led] << 4) | leds[led + 1];
        Serial.write(buf, 34);

        arcDirty = 0;
    }
*/
}
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

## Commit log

2024-09-12 Add KiCAD project
    [Btns.kicad_pcb, Btns.kicad_sch, btns_board.kicad_pcb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]
2024-10-10 Update Btns_Pico.ino
    Fix flip led matrix
    [Btns_Pico.ino]

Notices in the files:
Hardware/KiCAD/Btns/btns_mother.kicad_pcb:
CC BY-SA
